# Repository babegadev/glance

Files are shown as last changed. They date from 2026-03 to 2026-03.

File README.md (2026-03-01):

# Glance

> Your life, at a glance.

Glance is a physical display of the things that matter to you — friends, habits, practices. Each one is a hexagonal puck on your wall or desk. Each one glows. Each one has a heartbeat.

Let it slip, the pulse slows. Ignore it long enough, it flatlines. Press it when you've done the thing, it comes back to life.

No notifications. No streaks. No score. Just a honeycomb that goes quiet when your life does.

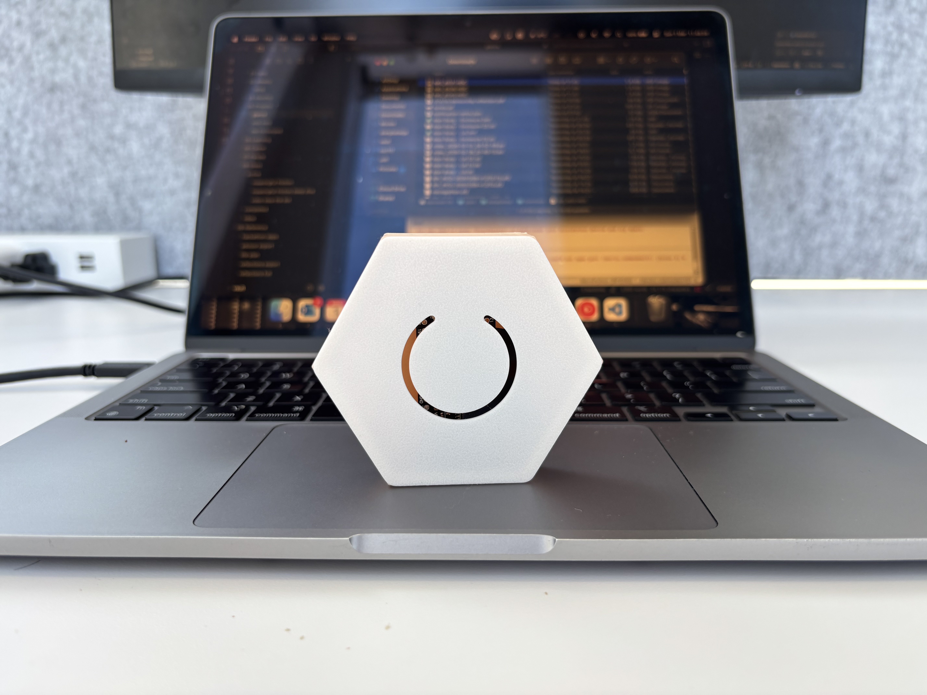
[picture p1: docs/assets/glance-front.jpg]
Glance


## How it works

Each node pulses at a rate tied to how long it's been since you last pressed it. Fresh: full brightness, ~60bpm. A few days gone: dimmer, slower. Too long: dark. The label disappears with the light.

Press the node. It flares back on.

Decay speed is configurable per node — a daily habit fades faster than a weekly one.

## The hardware

Nodes are identical hexagonal pucks, about 70mm across. They snap together magnetically, and power runs between them through contacts in the edges. One USB-C cable in, the rest of the cluster follows.

Works mounted on a wall (a metal backing plate, nodes snap on) or on a desk (a weighted angled stand). Same nodes either way, just a different base.

The goal is that it looks like a piece of art before it looks like a gadget.

## Status

Early stage. Currently breadboarding the firmware and interaction feel before moving to a custom PCB.

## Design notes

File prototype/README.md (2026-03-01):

# Prototype

A single-node proof of concept for the decay and breathing mechanism. No custom PCB, no enclosure — just the core interaction running on a YD-RP2040.

## Hardware

**YD-RP2040** — used because it has a built-in NeoPixel LED (GPIO 23) and a user button (GPIO 24), so no wiring needed to test the core loop. The NeoPixel uses the WS2812B protocol, same as the LEDs planned for the final hardware.

There's also an external trigger input on GPIO 2 — short it to GND to simulate a press without using the onboard button.

## What it tests

- Breathing animation that slows and dims as time passes since last press
- Flatline behavior when the decay window expires
- Button press → revive animation (bloom, hold, dissolve back to main color)
- Boot animation

## Settings

Everything is configurable at the top of `main.py`:

| Setting | Default | What it does |
|---|---|---|
| `BPM` | 12 | Breathing rate at full life |
| `BPM_MIN` | 10 | Slowest breath before flatline |
| `DECAY_SECONDS` | 4 | Time from full life to flatline |
| `MAX_BRIGHTNESS` | 1.0 | Global brightness cap |
| `MAIN_COLOR` | warm white | Resting color |
| `ACCENT_COLOR` | purple | Button press burst color |

`DECAY_SECONDS` is set low (4s) for fast iteration. In production, this would be days.

## Running it

Copy `main.py` to the root of the YD-RP2040 via Thonny or `mpremote`. It runs on boot.

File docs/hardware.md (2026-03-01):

# Hardware

## Form factor

Hexagonal pucks, ~70mm flat-to-flat, ~15–20mm thick. Flat-top orientation — flat edges on top and bottom, pointy on the sides. Nodes are all identical and fully interchangeable.

The cluster grows in any direction. Add a node when you start something new, pull one off when you let it go.

## Enclosure

Goal is for it to read as art before it reads as tech. Options being explored:

- Frosted/translucent resin — light diffuses evenly through the whole body
- Wood veneer face with light bleeding through the grain
- Matte white or warm grey with soft edge glow
- Brushed aluminum frame with frosted acrylic face

No visible screws, seams, or components from the front.

## Lighting

The whole hex should glow, not just a point. Options:

- **Full-body diffusion** — LED(s) centered inside a translucent shell, node itself is the light source
- **Edge glow** — LEDs around the perimeter, light bleeds inward, darker center
- **Underglow bleed** — LEDs on the back, light spills onto the wall behind the node. When the cluster is healthy, the whole wall section is bathed in soft light
- **Hybrid** — full-body diffusion + underglow. Node glows and casts light on the wall

When a node flatlines, the dark gap in the honeycomb is the signal. No badge, no alert — just absence.

## Button

The node should look like a solid seamless object. Options:

- **Whole-body press** — spring-mounted front plate, ~1–2mm travel, the entire face is the button
- **Magnetic press** — front plate held by magnets with a small gap, press clicks it inward against a switch, magnets return it
- **Hidden microswitch** — slightly recessed center area flexes inward when pressed

Whole-body or magnetic press are preferred — both keep the seamless look and feel more satisfying.

## Labels

- **Backlit cutout** — icon cut through an opaque top layer, backed by the diffuser. Glows when alive, invisible when flatlined. The label only exists when the habit does.
- **Color coding** — each node a distinct color, no text. You learn the map.
- Likely a hybrid of both: color for recognition at a distance, icon for up close.

## Mounting

### Wall mount

A laser-cut steel backing plate mounts to the wall (2–4 hidden screws). Nodes snap to it magnetically — no individual fasteners. The cluster can be rearranged freely without touching the wall.

A **Powerizer** — a small magnetic accessory — snaps onto any free edge of any node. One USB-C cable in, done.

### Desktop stand

A low-profile wedge (~15° tilt) holds the cluster at a comfortable viewing angle. Weighted base (cast concrete, steel-filled resin, or a hidden weight bar) so it doesn't tip when a node is pressed. Powerizer is built into the back of the stand — USB-C in, power feeds up through the bottom row of nodes.

Same nodes work in both modes.

---

## Electronics (per node)

| Component | Part | Notes |
|---|---|---|
| MCU | ATtiny1614 | Real I2C, 16KB flash, 5V native, UPDI programming |
| Crystal | 32.768kHz, 12.5pF | Sleep-based timekeeping, no external RTC |
| LED | SK6812 ×2 | WS2812B-compatible, better low-brightness uniformity |
| Schottky diode | BAT54C (dual SOT-23) ×3 | Power OR-ing, reverse protection, backfeed prevention |
| PTC fuse | Bourns MF-MSMF110 ×6 | Per-edge overcurrent protection, self-resetting |
| DIP switch | DIP-6 | 3 switches for decay speed (8 presets), 3 for color (8 options) |
| Magnets | N52 neodymium disc, 6×3mm ×12 | 2 per edge — alignment, hold force, orientation enforcement |
| Edge contacts | Gold-plated PCB pads | VCC + GND per edge, 12 contacts total |
| Decoupling caps | 100nF MLCC 0402 ×4 | — |
| Load caps | 12pF MLCC 0402 ×2 | Crystal load capacitance |
| PCB | Custom hex, 2-layer | KiCad, fabricated at JLCPCB |

No LDO — 5V rail throughout. Power comes in exclusively through edge contacts.

## Power architecture

One cable powers the whole cluster. Nodes have no USB-C port — power enters via a **Powerizer** accessory that snaps onto any free edge. From there it flows node to node through magnetic edge contacts.

### Edge contact layout

Every edge is identical:

```
[ magnet ][ VCC (top) | GND (bottom) ][ magnet ]
```

VCC and GND are stacked vertically (not side by side) so face-to-face mirroring never crosses the rails.

### Schottky OR-ing

All 6 edge VCC inputs go through a Schottky diode before joining the internal rail:

```
Edge 0–5 VCC ──[D1–D6]──┬── VCC Rail ──► MCU, LEDs
USB-C VBUS   ──[D7]─────┘   (Powerizer only)

Edge 0–5 GND ──[PTC fuse each]──── GND Rail
```

This lets multiple edges receive power simultaneously, blocks reverse current, and prevents backfeed into neighboring nodes.

**Components:** BAT54C (dual Schottky, SOT-23) — 3 packages per node covers all 6 edges. Bourns MF-MSMF110 PTC fuses, 150mA hold / 300mA trip.

### Magnet polarity

Alternating N-S-N-S-N-S clockwise from the top edge:

```
        top [N]
upper-left [S]   [S] upper-right
lower-left [N]   [N] lower-right
        bottom [S]
```

In a hex tessellation, opposing edges are always 3 positions apart — which in an alternating pattern are always opposite polarity. So touching edges always attract, in all 6 neighbor positions. Nodes rotated by 60°, 180°, or 300° repel — making wrong placement physically impossible.

## Powerizer

A standalone accessory. No MCU, no LED.

| Component | Part |
|---|---|
| USB-C connector | Power-only, 2-pin |
| Magnets | N52 disc, 6×3mm ×2 |
| Contact pins | Pogo pins, VCC + GND |
| Enclosure | Flat puck or half-hex, FDM or cast |

The desktop stand has a Powerizer built into its back face. The wall mount Powerizer is a separate snap-on puck.

## Cost estimate (qty 50–100)

| Scenario | Per-node cost |
|---|---|
| Electronics only | ~$4.50 |
| + FDM enclosure | ~$5.50 |
| + Resin print enclosure | ~$7.00 |
| + Cast resin enclosure | ~$10.00+ |

Costs drop ~20–30% at qty 500+, primarily from PCB and magnet bulk pricing.

Each node draws ~100–200mA peak. A 2A USB-C supply handles 10–15 nodes comfortably.

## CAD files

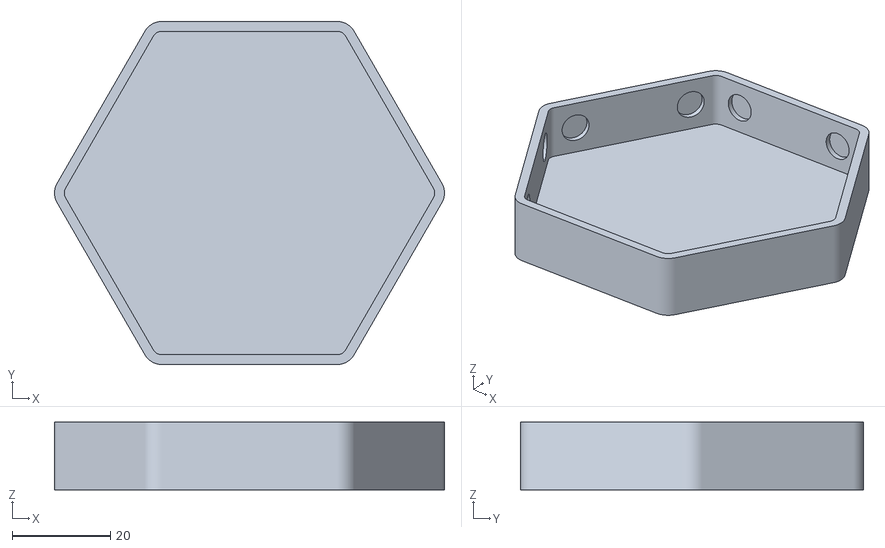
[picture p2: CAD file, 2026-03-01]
cad/v0-prototype/main-body.stl
79.6 x 70.0 x 13.8

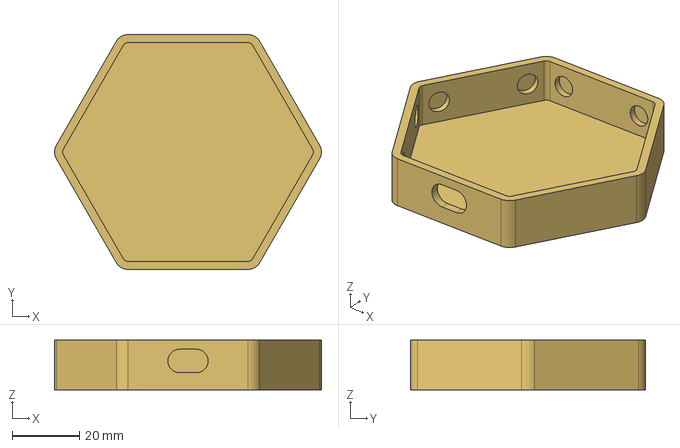
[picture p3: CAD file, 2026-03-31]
cad/v0.1/Main Body - Enclosure.step
79.6 x 70.0 x 14.8 mm

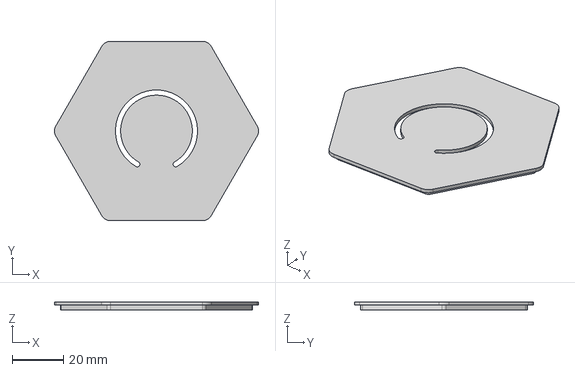
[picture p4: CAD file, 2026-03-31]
cad/v0.1/Main Body - Lid.step
79.6 x 70.0 x 3.20 mm

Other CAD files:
cad/v0-prototype/main-body-with-usb-c.stl
cad/v0.1/main body.3mf
cad/v0-prototype/lid-with-frame.stl
cad/v0.1/lid.3mf
cad/v0.1/lid.stl
cad/v0.1/main body.stl

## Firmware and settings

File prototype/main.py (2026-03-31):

"""
Glance — Single Node Prototype
==================================
YD-RP2040: WS2812 NeoPixel on GPIO 23, USR button on GPIO 24.

Configure everything in the SETTINGS block below.
Press USR for a dopamine hit.
"""

import machine
import neopixel
import time
import math

# ╔═════════════════════════════════════════════════════════════════════════╗
# ║  SETTINGS — tweak these                                               ║
# ╚═════════════════════════════════════════════════════════════════════════╝

NEOPIXEL_PIN   = 23
BUTTON_PIN     = 24          # USR button
EXT_BUTTON_PIN = 2           # external trigger — short GPIO2 to GND

# Breathing
BPM            = 12          # breaths per minute at full life (normal resting human)
BPM_MIN        = 10           # slowest breathing before flatline
DECAY_SECONDS  = 4          # seconds from full life to flatline
MAX_BRIGHTNESS = 0.9         # global cap (0.0–1.0)
MIN_BRIGHTNESS = 0.5        # dimmest the breathing trough gets

# Colors (R, G, B)  — some presets:
#   Warm white: (255, 220, 180)   Cool white: (255, 255, 255)
#   Amber:      (255, 140, 20)    Candle:     (255, 100, 30)
MAIN_COLOR     = (255, 180, 107)   # resting breathe color
ACCENT_COLOR   = (100, 40, 255)    # button press color burst

# Animation
COLOR_SHIFT_MS = 8000        # total animation length after press

# ╔═════════════════════════════════════════════════════════════════════════╗
# ║  END SETTINGS                                                          ║
# ╚═════════════════════════════════════════════════════════════════════════╝

# ---------------------------------------------------------------------------
# HARDWARE
# ---------------------------------------------------------------------------
np  = neopixel.NeoPixel(machine.Pin(NEOPIXEL_PIN), 1)
btn = machine.Pin(BUTTON_PIN, machine.Pin.IN, machine.Pin.PULL_UP)
ext = machine.Pin(EXT_BUTTON_PIN, machine.Pin.IN, machine.Pin.PULL_UP)

# ---------------------------------------------------------------------------
# STATE
# ---------------------------------------------------------------------------
last_press_ms  = time.ticks_ms()
press_time_ms  = 0
anim_phase     = "idle"       # idle | animating

# Track what the LED is actually showing right now
current_color  = MAIN_COLOR
current_scale  = 0.0
breath_phase   = 0.0          # 0.0–1.0, tracks where we are in the breath cycle
last_frame_ms  = time.ticks_ms()

# Snapshot of LED state at moment of button press
snap_color     = MAIN_COLOR
snap_scale     = 0.0

# ---------------------------------------------------------------------------
# COLOR MATH
# ---------------------------------------------------------------------------
def lerp(a, b, t):
    return a + (b - a) * t

def lerp_color(c1, c2, t):
    t = max(0.0, min(1.0, t))
    return (lerp(c1[0], c2[0], t),
            lerp(c1[1], c2[1], t),
            lerp(c1[2], c2[2], t))

def ease_in_out_sine(t):
    return -(math.cos(math.pi * t) - 1) / 2

# ---------------------------------------------------------------------------
# LED OUTPUT
# ---------------------------------------------------------------------------
def set_led(color, scale):
    """color: (r,g,b) 0–255, scale: 0–1."""
    np[0] = (
        min(255, int(color[0] * scale * MAX_BRIGHTNESS)),
        min(255, int(color[1] * scale * MAX_BRIGHTNESS)),
        min(255, int(color[2] * scale * MAX_BRIGHTNESS)),
    )
    np.write()

# ---------------------------------------------------------------------------
# BREATHING
# ---------------------------------------------------------------------------
def elapsed_seconds():
    return time.ticks_diff(time.ticks_ms(), last_press_ms) / 1000

def decay_fraction():
    return min(elapsed_seconds() / DECAY_SECONDS, 1.0)

def breath_params(frac):
    if frac >= 1.0:
        return (0, 0.0, 0.0)

    # Use a smooth curve instead of linear so the final fade is gentle
    # This spends more time in the bright range and fades slowly at the end
    alive = (1.0 - frac) ** 0.7

    bpm = BPM_MIN + (BPM - BPM_MIN) * alive
    ceiling = MIN_BRIGHTNESS + (1.0 - MIN_BRIGHTNESS) * alive
    floor   = MIN_BRIGHTNESS * alive
    return (bpm, ceiling, floor)

def breath_value(ceiling, floor, phase):
    if ceiling <= 0:
        return 0.0

    # Real human breathing pattern (from research):
    #   I:E ratio ~1:2, with a post-exhale rest pause.
    #
    #   Inhale   25%  — active, slightly faster rise
    #   Exhale   50%  — passive elastic recoil, slow and gentle
    #   Rest     25%  — quiet pause, nearly still, before next inhale

    if phase < 0.25:
        # Inhale
        t = phase / 0.25
        v = ease_in_out_sine(t)

    elif phase < 0.75:
        # Exhale — twice as long as inhale
        t = (phase - 0.25) / 0.50
        v = 1.0 - ease_in_out_sine(t)

    else:
        # Rest pause
        t = (phase - 0.75) / 0.25
        v = 0.04 * math.sin(t * math.pi)

    return floor + v * (ceiling - floor)

def final_fade_scale(frac):
    """In the last 10% of decay, smoothly multiply everything toward 0."""
    fade_start = 0.85
    if frac < fade_start:
        return 1.0
    t = (frac - fade_start) / (1.0 - fade_start)
    # Smooth S-curve to zero
    return (1.0 - ease_in_out_sine(t))

# ---------------------------------------------------------------------------
# BUTTON PRESS ANIMATION — blends from wherever we are
#
# Timeline:
#   0–2.0s       BLOOM     — from current state, drift into accent color
#   2.0–5.0s     HOLD      — accent breathes slowly, one deep breath
#   5.0–8.0s     DISSOLVE  — melt back into main color at current decay level
# ---------------------------------------------------------------------------
BLOOM_MS    = 2000
HOLD_MS     = 5000
# DISSOLVE runs until COLOR_SHIFT_MS

def button_animation(now):
    """Animate from snapshot state through accent and back."""
    global anim_phase

    elapsed = time.ticks_diff(now, press_time_ms)

    if elapsed > COLOR_SHIFT_MS:
        anim_phase = "idle"
        return None

    # --- PHASE 1: BLOOM (0 → 2s) ---
    # From wherever we were, drift smoothly into accent at full brightness
    if elapsed < BLOOM_MS:
        t = ease_in_out_sine(elapsed / BLOOM_MS)

        color = lerp_color(snap_color, ACCENT_COLOR, t)
        scale = lerp(snap_scale, 0.85, t)

        return (color, scale)

    # --- PHASE 2: HOLD (2s → 5s) ---
    # Breathe deeply in accent. Subtle drift keeps it alive.
    elif elapsed < HOLD_MS:
        t = (elapsed - BLOOM_MS) / (HOLD_MS - BLOOM_MS)

        breath = math.sin(t * math.pi) ** 2
        scale = 0.55 + 0.35 * breath

        # Gentle hue wander
        drift = math.sin(t * math.pi * 2) * 0.12
        color = lerp_color(ACCENT_COLOR, MAIN_COLOR, max(0, drift))

        return (color, scale)

    # --- PHASE 3: DISSOLVE (5s → 8s) ---
    # Melt back into main color, land at current breathing level
    else:
        t = ease_in_out_sine((elapsed - HOLD_MS) / (COLOR_SHIFT_MS - HOLD_MS))

        color = lerp_color(ACCENT_COLOR, MAIN_COLOR, t)

        # Land where normal breathing currently is
        frac = decay_fraction()
        bpm, ceiling, floor = breath_params(frac)
        fade = final_fade_scale(frac)
        target = breath_value(ceiling, floor, breath_phase) * fade
        scale = lerp(0.6, max(target, 0.1), t)

        return (color, scale)

# ---------------------------------------------------------------------------
# BUTTON HANDLER
# ---------------------------------------------------------------------------
last_btn_state = 1
last_ext_state = 1
debounce_ms    = 200
last_debounce  = 0

def check_button():
    global last_press_ms, press_time_ms, anim_phase
    global last_btn_state, last_ext_state, last_debounce
    global snap_color, snap_scale

    now = time.ticks_ms()
    if time.ticks_diff(now, last_debounce) < debounce_ms:
        return

    # Check both inputs — either one triggers
    btn_state = btn.value()
    ext_state = ext.value()

    btn_pressed = btn_state == 0 and last_btn_state == 1
    ext_pressed = ext_state == 0 and last_ext_state == 1

    last_btn_state = btn_state
    last_ext_state = ext_state

    if btn_pressed or ext_pressed:
        last_debounce = now
        snap_color = current_color
        snap_scale = current_scale
        last_press_ms = now
        press_time_ms = now
        anim_phase = "animating"

# ---------------------------------------------------------------------------
# BOOT — a slow, warm awakening
# ---------------------------------------------------------------------------
def first_breath():
    steps = 100
    for i in range(steps):
        t = i / steps
        scale = MIN_BRIGHTNESS + (0.4 - MIN_BRIGHTNESS) * (t ** 2)
        set_led(MAIN_COLOR, scale)
        time.sleep_ms(18)
    time.sleep_ms(150)

# ---------------------------------------------------------------------------
# MAIN
# ---------------------------------------------------------------------------
def main():

    print("Life Wall — YD-RP2040")
    print(f"BPM: {BPM} | Decay: {DECAY_SECONDS}s")
    print(f"Buttons: USR (GPIO{BUTTON_PIN}) + EXT (GPIO{EXT_BUTTON_PIN} → GND)")
    print("Press USR for dopamine.\n")

    first_breath()

    global anim_phase, current_color, current_scale
    global breath_phase, last_frame_ms
    last_debug = time.ticks_ms()
    breath_count = 0
    prev_phase = 0.0

    while True:
        check_button()
        now = time.ticks_ms()
        dt_ms = time.ticks_diff(now, last_frame_ms)
        last_frame_ms = now

        # Advance breath phase based on current BPM
        frac = decay_fraction()
        bpm, ceiling, floor = breath_params(frac)

        if bpm > 0:
            period_ms = 60_000 / bpm
            breath_phase += dt_ms / period_ms
            if breath_phase >= 1.0:
                breath_phase -= 1.0

        # Debug: count breaths
        if breath_phase < prev_phase:
            breath_count += 1
        prev_phase = breath_phase
        if time.ticks_diff(now, last_debug) > 10_000:
            actual_bpm = breath_count * 6
            print(f"Target BPM: {bpm:.1f} | Actual: ~{actual_bpm} | phase: {breath_phase:.2f}")
            breath_count = 0
            last_debug = now

        # Button animation takes priority
        if anim_phase != "idle":
            result = button_animation(now)
            if result is not None:
                color, scale = result
                current_color = color
                current_scale = scale
                set_led(color, scale)
                time.sleep_ms(10)
                continue
            else:
                anim_phase = "idle"

        # Normal breathing
        fade = final_fade_scale(frac)

        if ceiling <= 0 and fade <= 0:
            current_color = MAIN_COLOR
            current_scale = 0.0
            np[0] = (0, 0, 0)
            np.write()
            time.sleep_ms(50)
        else:
            scale = breath_value(ceiling, floor, breath_phase) * fade
            current_color = MAIN_COLOR
            current_scale = scale
            set_led(MAIN_COLOR, scale)
            time.sleep_ms(15)

if __name__ == "__main__":
    main()

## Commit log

2026-03-01 Added v0 prototype files and hardware.md
    [lid-with-frame.stl, main-body-with-usb-c.stl, main-body.stl]
2026-03-07 v0.1 CAD: made wall thicker to account for magnets, added bambu files, updated lid accordingly
    [lid.3mf, lid.stl, main body.3mf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]
2026-03-31 Added STEP files for stasis
    [Main Body - Enclosure.step, Main Body - Lid.step]
